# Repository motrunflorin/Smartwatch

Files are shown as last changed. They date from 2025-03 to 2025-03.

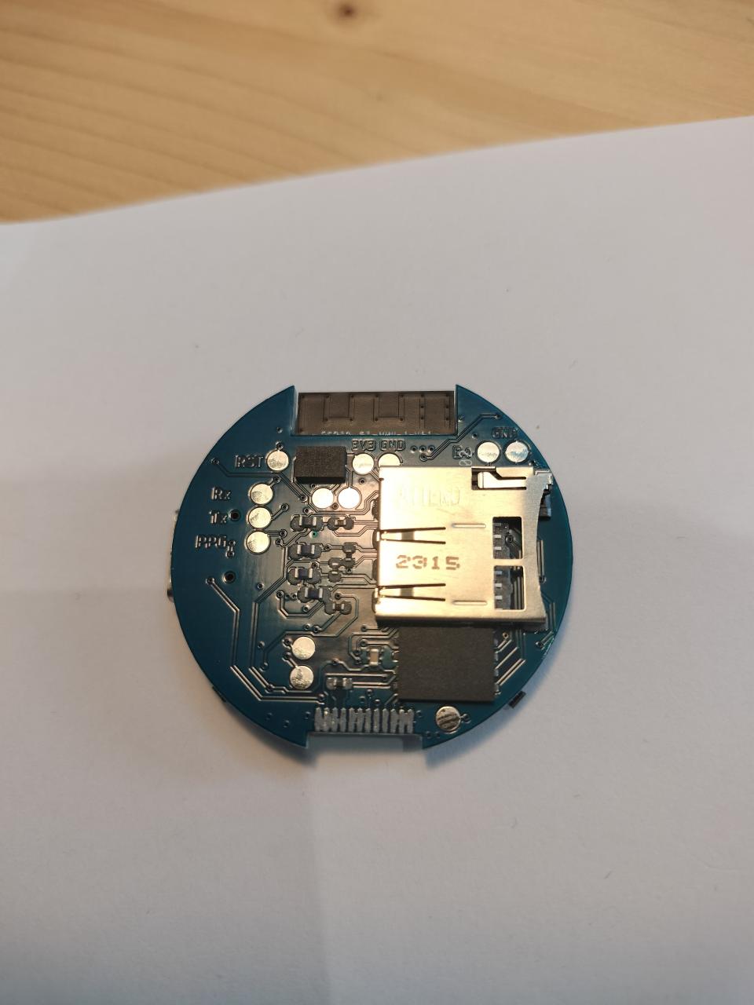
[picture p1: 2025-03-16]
bottom_layer.jpeg

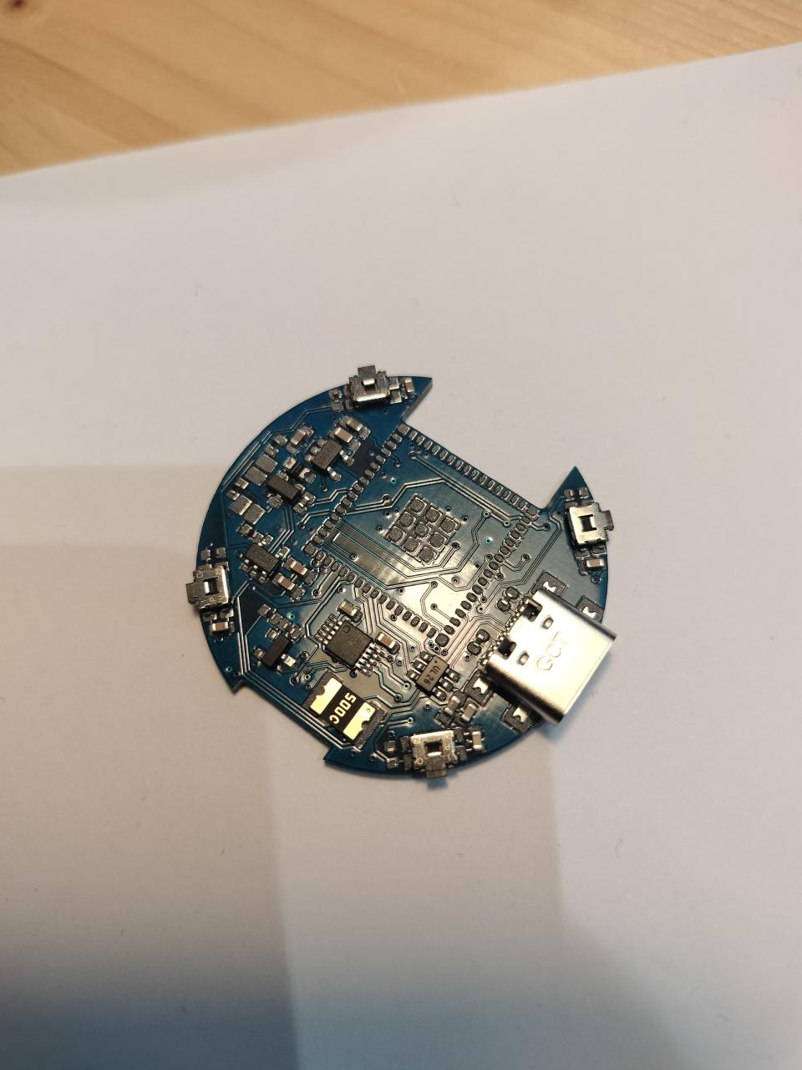
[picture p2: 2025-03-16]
top_layer.jpeg

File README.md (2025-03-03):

Functionalities:

* Wi-Fi and BLE communication via ESP32
* IMU 6-axis BMI085 for motion sensing
* DRV2605L for haptic feedback
* LiPo battery with MCP73831 charging circuit
* USB-C port for programming and charging
* 1.28-inch LCD display, 240x240 pixels for visual output
* Electronics must fit into the provided case

(All datasheets and schematics are in the Components folder)

Constraints:

* No straight angles in traces.
* Power traces must meet the required dimensions.
* Decoupling capacitors (100nF) should be placed as close as possible to the power pins of modules and ICs.
* For double-sided boards, avoid vias in power traces.
* Main components should be placed according to the mechanical dimension and placement document.
* Power traces (VCC, VUSB, VBUS, 3V3, etc.) should have a width of 0.3mm, and data signals at least 0.125mm.
* The ESP32 antenna should be placed toward the PCB edge, with the PCB cutout beneath it.

Notes and Recommendations:

* Use SMD resistors and capacitors in 0402 package, unless specified otherwise (e.g., 0603, tantalum).
* Component placement should be on the TOP layer (except for test pads, SD card socket, LCD connector, and NOR Flash).
* Routing can be on both top and bottom layers. If using two layers, ensure the ground plane is appropriately designed.
* For DRC checks, load the verification file from the provided archive.
* Apply Via Stitching between the two ground planes, especially near the ESP32 module.
* Ignore "Only INPUT pins on NET ID" error.
* Do not route signals under the ESP32 antenna; the area beneath it must be cut out to minimize interference.
* Errors due to button, header, and USB port placement are disregarded.
* Test pads should be placed only on the back of the PCB, clearly marked in silkscreen with signal names.
* Use the provided library ([hector_watch.zip file]) for component symbols and footprints, except for:
    - Buttons ([button.pdf file])
    - LCD connector (draw your own footprints based on the LCD datasheet).

Files:

* Schematics: Schematics.zip file
* DRC check: DRC_check.zip file
* PCB Dimensions & Placement: [dimensions.pdf file]

Additional Notes:

* The recommended PCB dimensions and component placement can be found in the [dimensions.pdf file], with all measurements in mm.
* The placement is just a recommendation to ensure the PCB buttons align with the physical buttons on the case.
* You are free to modify the placement, as long as you also adjust the case.
* Additionally, modify the case to allow access to the SD card and USB-C port if they do not align properly.

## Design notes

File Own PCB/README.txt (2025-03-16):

for the power traces (3V3), I maintained a width of 0.3 mm, while the rest have 0.127 mm;
!! correction: due to files not being saved properly, I had sync errors between schematics and PCB, and I had to delete the 3V3 traces and modify them with a width of 0.127 mm;

I couldn't group the test pads in a regular shape, and the TX test pad is not in the grouping in order to connect it to the corresponding pin;
(initially, I designed the test pad arrangement as three distinct groups, placed as strategically as possible near the pins they needed to be connected to, in order to have the most optimal traces);

the 100 nF decoupling capacitors were placed as close as possible to the power supply pins;

the main components were placed according to the specifications in the dimensions document, with almost negligible errors, on the order of 10^-3 mm;

the ESP32 module's antenna was placed towards the outer edge of the PCB, and the PCB was cut out as precisely as possible under the antenna;

the test pads, the SD card socket, the LCD connector, and the NOR Flash circuit were placed on the Top layer;

the footprints for the buttons and the LCD display connector were made according to the datasheet;

I tried as much as possible to keep all the component groupings from the schematics together, such as the diode grouping, for example;

I also tried to position the components as close as possible to their corresponding connections from the schematics to the PCB, such as the R1-USB resistor of the USB4110-GF-A module;

ERRORS: resistors R11 and R9 were not connected as I couldn't find a viable trace;

silkscreen was done for the test pads with a width of 0.4 mm.

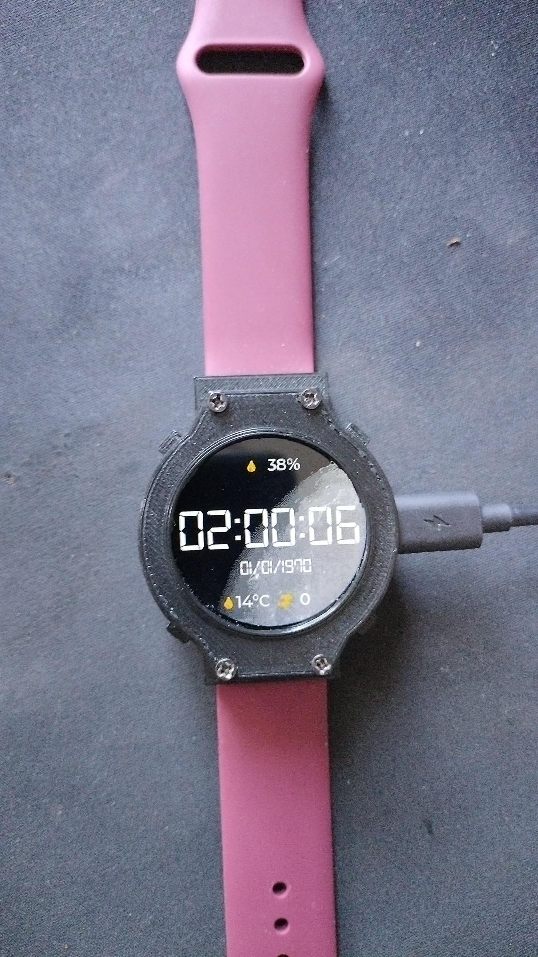
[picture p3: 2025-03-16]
finished.jpeg

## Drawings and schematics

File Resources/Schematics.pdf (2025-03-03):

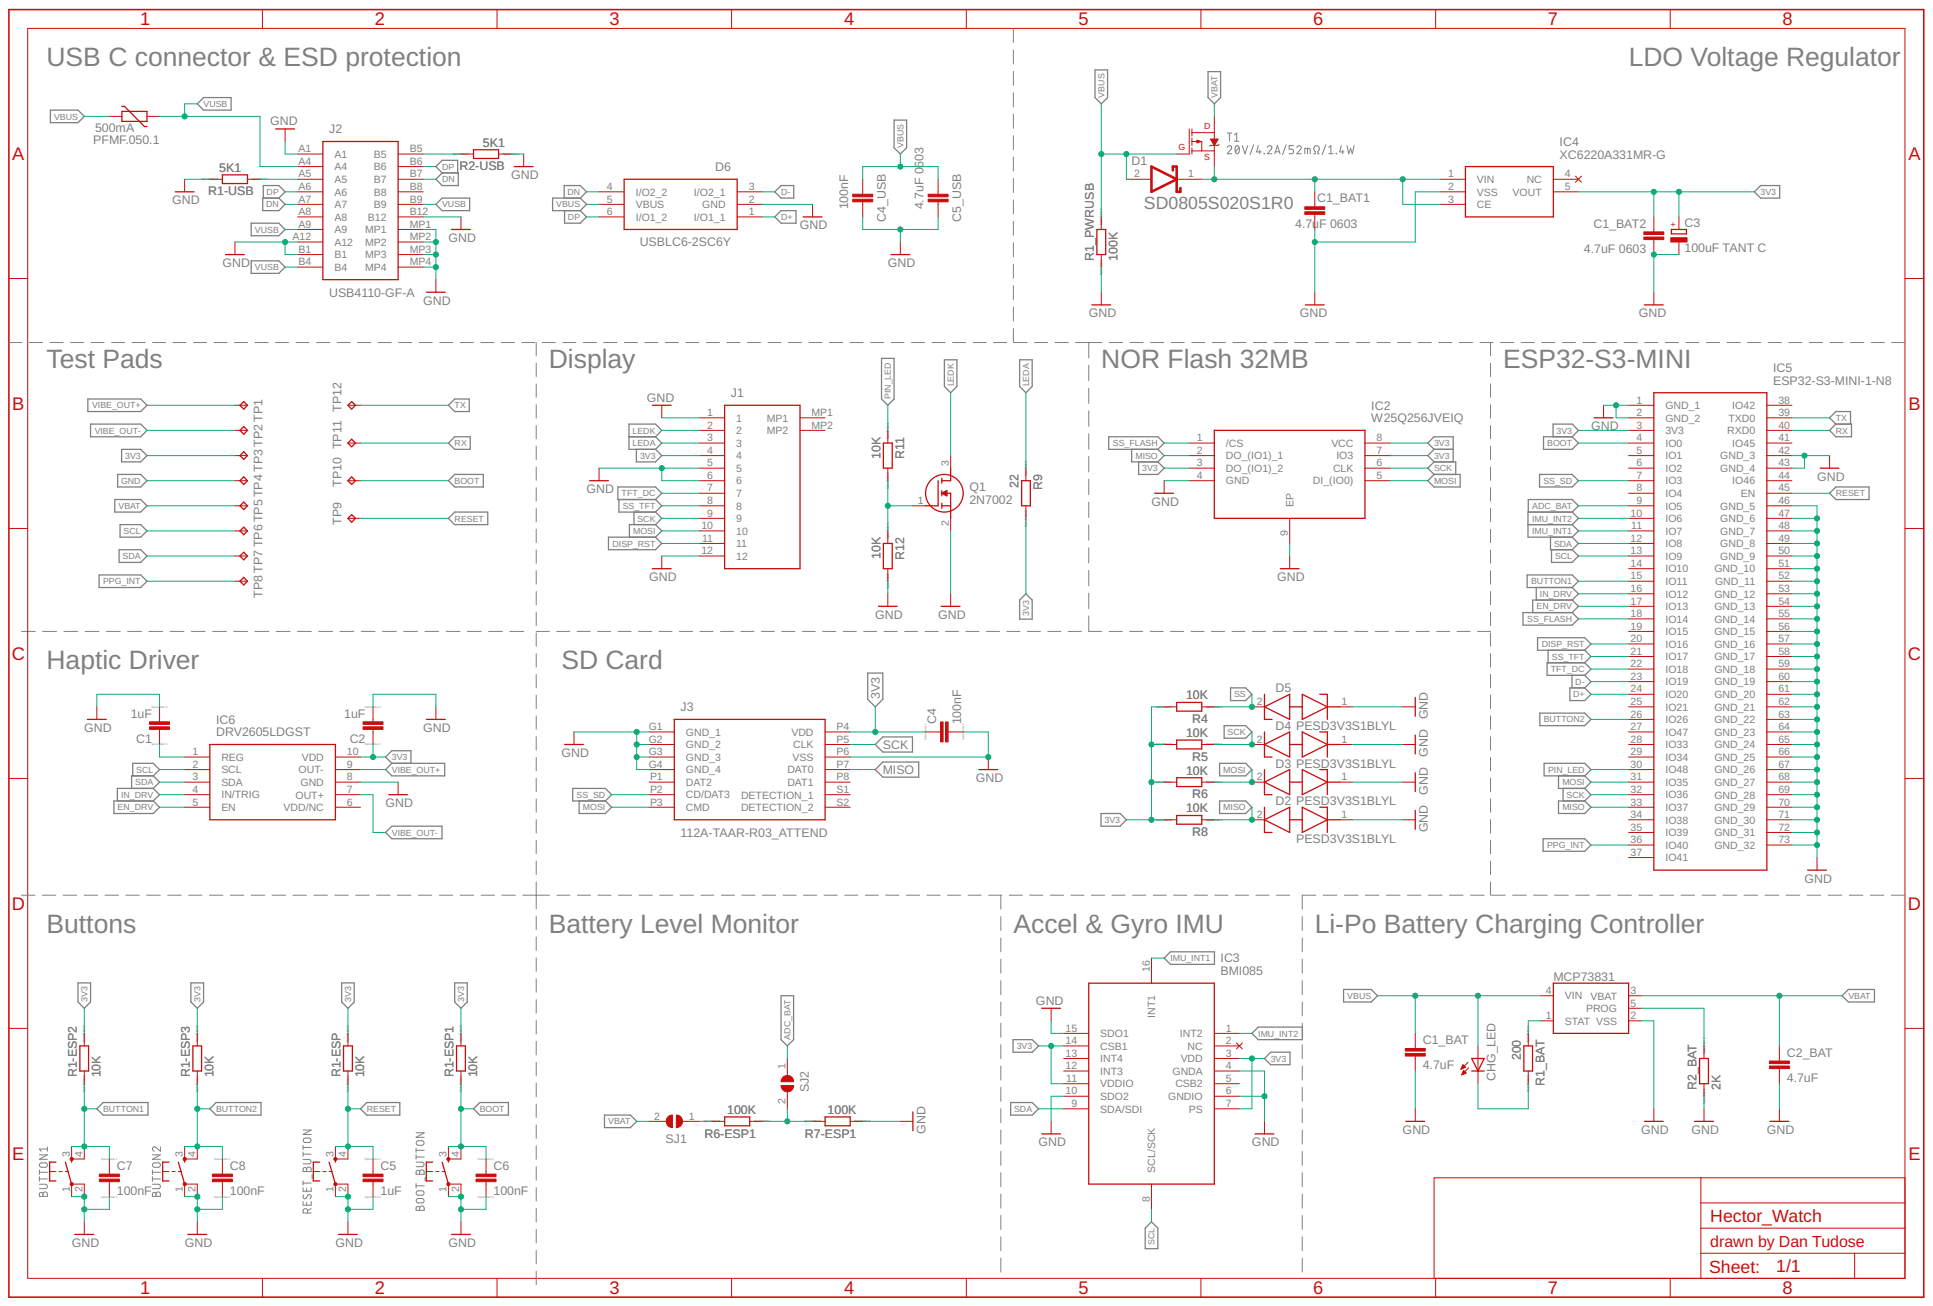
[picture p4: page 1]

USB C connector & ESD protection

SpiceOrder 1 SpiceOrder 2

SpiceOrder 1 SpiceOrder 2 SpiceOrder 1 SpiceOrder 2

IN_DRV 17 | 53 GND_13
EN_DRV 18 | 54 GND_14 55 GND_15

drawn by Dan Tudose Sheet:

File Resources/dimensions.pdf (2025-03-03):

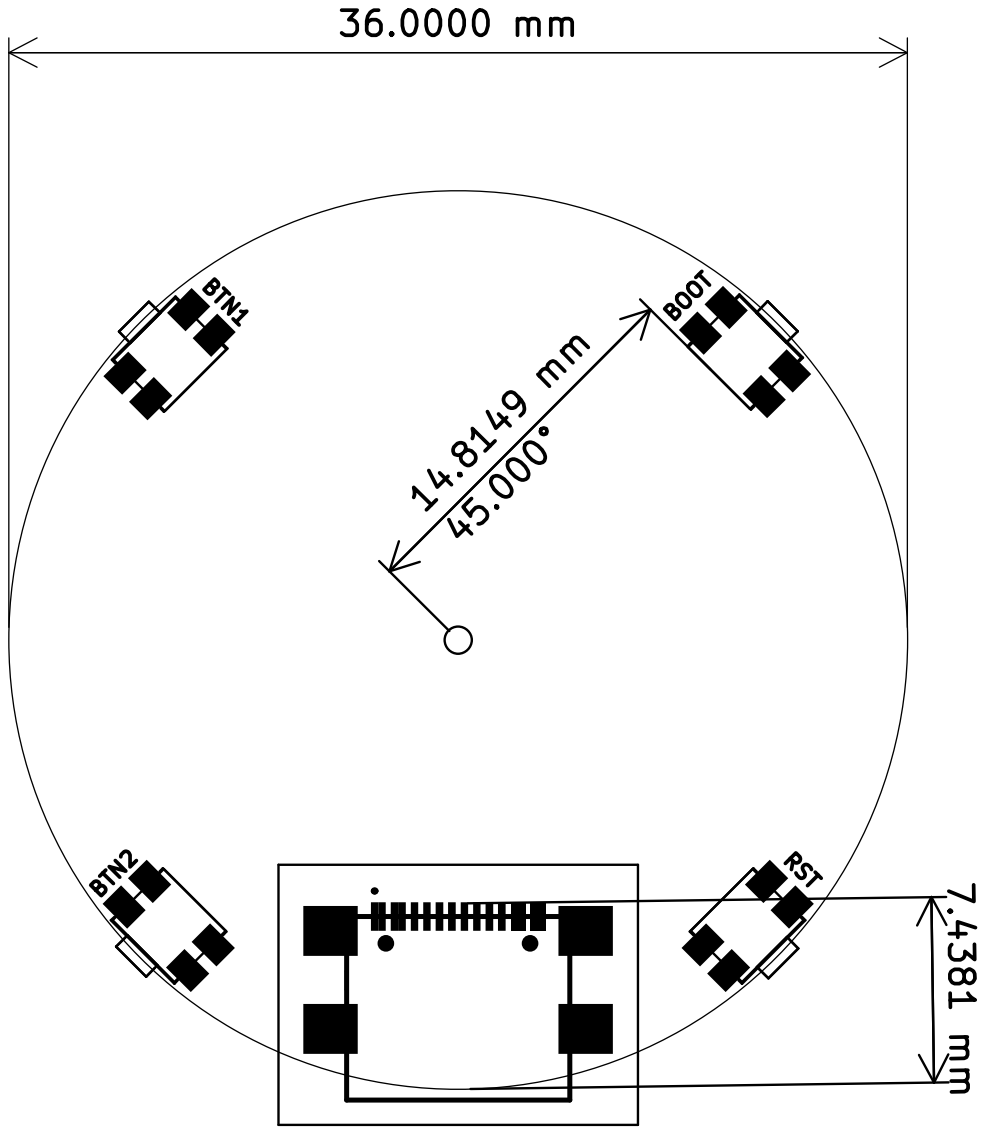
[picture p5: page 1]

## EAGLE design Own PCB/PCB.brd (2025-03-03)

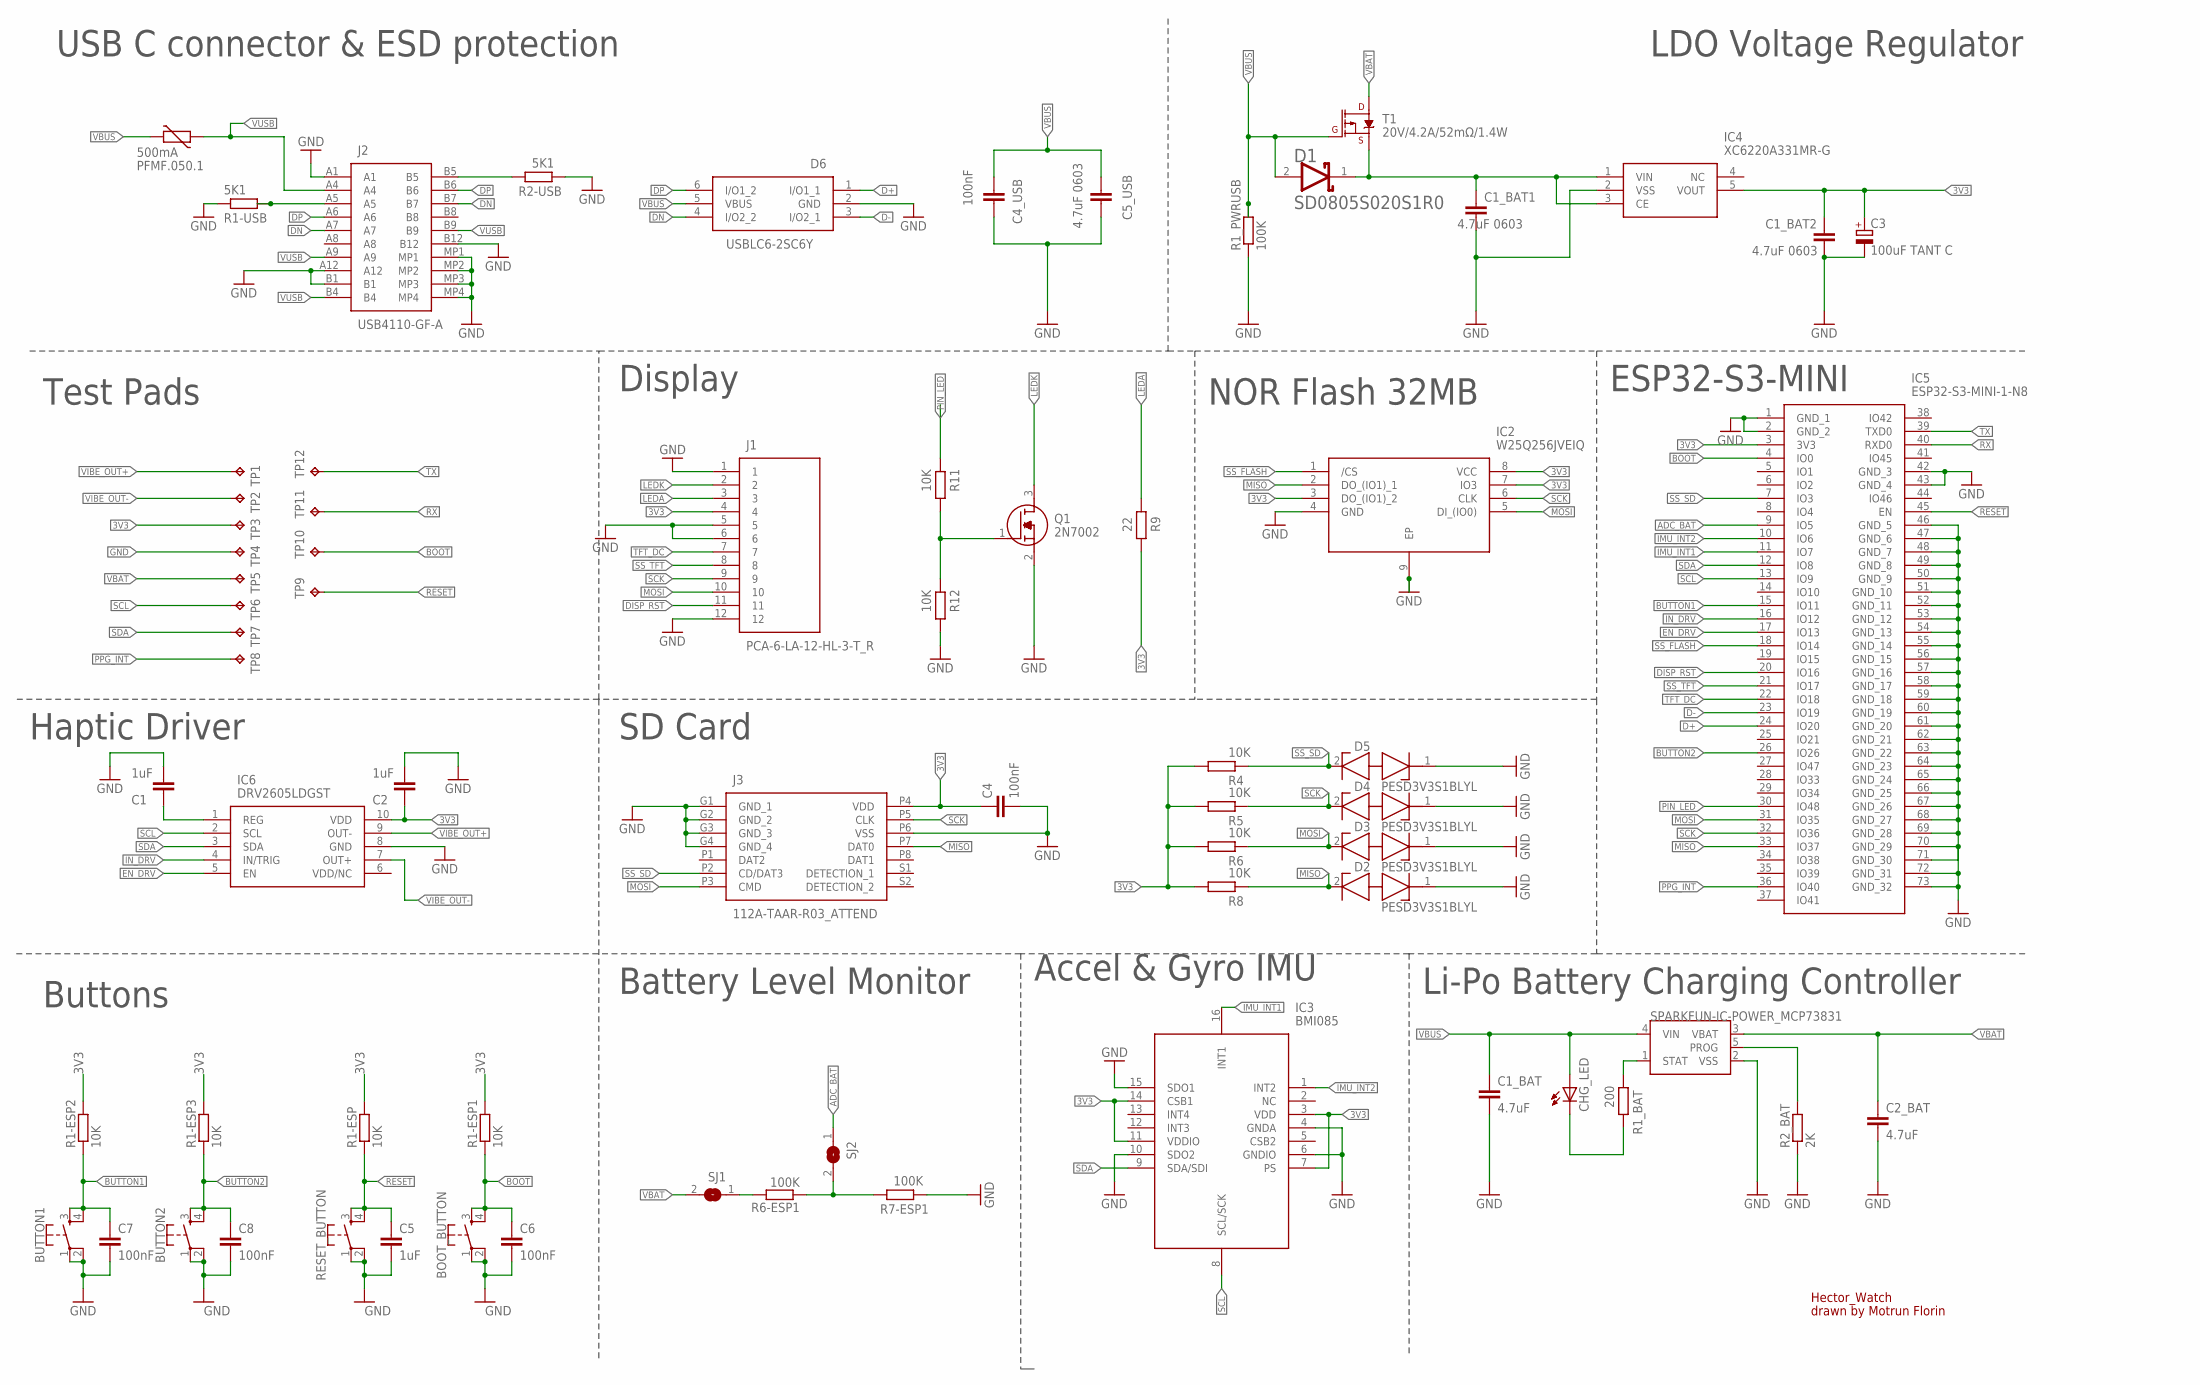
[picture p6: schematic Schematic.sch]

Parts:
BOOT_BUTTON: SPARKFUN-SWITCHES_MOMENTARY-SWITCH-SPST-2-SMD-4.6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; SPARKFUN-SWITCHES_TACTILE_SWITCH_SMD_4.6X2.8MM
BUTTON1, BUTTON2: SPARKFUN-SWITCHES_MOMENTARY-SWITCH-SPST-2-SMD-4.6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; SPARKFUN-SWITCHES_TACTILE_SWITCH_SMD_4.6X2.8MM
C1, C2, C5: 1uF; EAGLE-LTSPICE_C0402
C1_BAT, C2_BAT: 4.7uF; EAGLE-LTSPICE_C0402
C1_BAT1, C1_BAT2, C5_USB: 4.7uF 0603; RCL_C0603
C3: 100uF TANT C; CT3528
C4, C4_USB, C6, C7, C8: 100nF; EAGLE-LTSPICE_C0402
CHG_LED: ADAFRUIT_LEDCHIP-LED0603; ADAFRUIT_CHIP-LED0603
D1: AVX---SD0805S020S1R0_AVX_SD0805S020S1R0AVX_SD0805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; AVX---SD0805S020S1R0_AVX_SD0805S020S1R0_0
D2, D3, D4, D5: PESD3V3S1BLYL; PESD5V0S1BL315
D6: USBLC6-2SC6Y; SOT95P280X145-6N
IC2: W25Q256JVEIQ; SON127P800X600X80-9N
IC3: BMI085
IC4: XC6220A331MR-G; SOT95P280X120-5N
IC5: ESP32-S3-MINI-1-N8; ESP32S3MINI1N8
IC6: DRV2605LDGST; SOP50P490X110-10N
J1: PCA-6-LA-12-HL-3-T_R; PCA6LA12HL3TR
J2: USB4110-GF-A; USB4110GFA
J3: 112A-TAAR-R03_ATTEND; 112ATAARR03ATTEND
PFMF.050.1: 500mA; VARISTOR_CT/CN1812
Q1: 2N7002; SOT96P240X120-3N
R1-ESP, R1-ESP1, R1-ESP2, R1-ESP3, R4, R5, R6, R8, R11, R12: 10K; EAGLE-LTSPICE_R0402
R1-USB, R2-USB: 5K1; EAGLE-LTSPICE_R0402
R1_BAT: 200; EAGLE-LTSPICE_R0402
R1_PWRUSB, R6-ESP1, R7-ESP1: 100K; EAGLE-LTSPICE_R0402
R2_BAT: 2K; EAGLE-LTSPICE_R0402
R9: 22; EAGLE-LTSPICE_R0402
RESET_BUTTON: SPARKFUN-SWITCHES_MOMENTARY-SWITCH-SPST-2-SMD-4.6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; SPARKFUN-SWITCHES_TACTILE_SWITCH_SMD_4.6X2.8MM
SJ1, SJ2: SJ
T1: 20V/4.2A/52mΩ/1.4W; SPARKFUN-DISCRETESEMI_SOT23-3
TP1, TP2, TP3, TP4, TP5, TP6, TP7, TP8, TP9, TP10, TP11, TP12: TPTP20R; TP20R
U1: SPARKFUN-IC-POWER_MCP73831; SPARKFUN-IC-POWER_SOT23-5

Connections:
3V3: C1_BAT2.1, C2.2, C3.+, C4.1, IC2.3 (DO_(IO1)_2), IC2.7 (IO3), IC2.8 (VCC), IC3.3 (VDD), IC3.7 (PS), IC3.11 (VDDIO), IC3.14 (CSB1), IC4.5 (VOUT), IC5.3 (3V3), IC6.10 (VDD), J1.4, J3.P4 (VDD), R1-ESP.2, R1-ESP1.2, R1-ESP2.2, R1-ESP3.2, R4.1, R5.1, R6.1, R8.1, R9.1, TP3.TP
ADC_BAT: IC5.9 (IO5), SJ2.1
BOOT: BOOT_BUTTON.3, BOOT_BUTTON.4, C6.1, IC5.4 (IO0), R1-ESP1.1, TP10.TP
BUTTON1: BUTTON1.3, BUTTON1.4, C7.1, IC5.15 (IO11), R1-ESP2.1
BUTTON2: BUTTON2.3, BUTTON2.4, C8.1, IC5.26 (IO26), R1-ESP3.1
D+: D6.1 (I/O1_1), IC5.24 (IO20)
D-: D6.3 (I/O2_1), IC5.23 (IO19)
DISP_RST: IC5.20 (IO16), J1.11
DN: D6.4 (I/O2_2), J2.A7, J2.B7
DP: D6.6 (I/O1_2), J2.A6, J2.B6
EN_DRV: IC5.17 (IO13), IC6.5 (EN)
GND: BOOT_BUTTON.1, BOOT_BUTTON.2, BUTTON1.1, BUTTON1.2, BUTTON2.1, BUTTON2.2, C1.1, C1_BAT.2, C1_BAT1.2, C1_BAT2.2, C2.1, C2_BAT.2, C3.-, C4.2, C4_USB.1, C5.2, C5_USB.2, C6.2, C7.2, C8.2, D2.1 (K1), D3.1 (K1), D4.1 (K1), D5.1 (K1), D6.2 (GND), IC2.4 (GND), IC2.9 (EP), IC3.4 (GNDA), IC3.6 (GNDIO), IC3.10 (SDO2), IC3.15 (SDO1), IC4.2 (VSS), IC5.1 (GND_1), IC5.2 (GND_2), IC5.42 (GND_3), IC5.43 (GND_4), IC5.46 (GND_5), IC5.47 (GND_6), IC5.48 (GND_7), IC5.49 (GND_8), IC5.50 (GND_9), IC5.51 (GND_10), IC5.52 (GND_11), IC5.53 (GND_12), IC5.54 (GND_13), IC5.55 (GND_14), IC5.56 (GND_15), IC5.57 (GND_16), IC5.58 (GND_17), IC5.59 (GND_18), IC5.60 (GND_19), IC5.61 (GND_20), IC5.62 (GND_21), IC5.63 (GND_22), IC5.64 (GND_23), IC5.65 (GND_24), IC5.66 (GND_25), IC5.67 (GND_26), IC5.68 (GND_27), IC5.69 (GND_28), IC5.70 (GND_29), IC5.71 (GND_30), IC5.72 (GND_31), IC5.73 (GND_32), IC6.8 (GND), J1.1, J1.5, J1.6, J1.12, J2.A1, J2.A12, J2.B1, J2.B12, J2.MP1, J2.MP2, J2.MP3, J2.MP4, J3.G1 (GND_1), J3.G2 (GND_2), J3.G3 (GND_3), J3.G4 (GND_4), J3.P6 (VSS), Q1.2 (S), R1-USB.1, R1_PWRUSB.1, R2-USB.2, R2_BAT.1, R7-ESP1.2, R12.1, RESET_BUTTON.1, RESET_BUTTON.2, TP4.TP, U1.2 (VSS)
IMU_INT1: IC3.16 (INT1), IC5.11 (IO7)
IMU_INT2: IC3.1 (INT2), IC5.10 (IO6)
IN_DRV: IC5.16 (IO12), IC6.4 (IN/TRIG)
LEDA: J1.3, R9.2
LEDK: J1.2, Q1.3 (D)
MISO: D2.2 (K2), IC2.2 (DO_(IO1)_1), IC5.33 (IO37), J3.P7 (DAT0), R8.2
MOSI: D3.2 (K2), IC2.5 (DI_(IO0)), IC5.31 (IO35), J1.10, J3.P3 (CMD), R6.2
unnamed: J2.B5, R2-USB.1
unnamed: J2.A5, R1-USB.2
unnamed: C1.2, IC6.1 (REG)
unnamed: C1_BAT1.1, D1.1 (CATHODE), IC4.1 (VIN), IC4.3 (CE), T1.2 (S)
unnamed: CHG_LED.C, R1_BAT.1
unnamed: R6-ESP1.2, SJ1.1
unnamed: R6-ESP1.1, R7-ESP1.1, SJ2.2
unnamed: R2_BAT.2, U1.5 (PROG)
unnamed: Q1.1 (G), R11.1, R12.2
unnamed: R1_BAT.2, U1.1 (STAT)
PIN_LED: IC5.30 (IO48), R11.2
PPG_INT: IC5.36 (IO40), TP8.TP
RESET: C5.1, IC5.45 (EN), R1-ESP.1, RESET_BUTTON.3, RESET_BUTTON.4, TP9.TP
RX: IC5.40 (RXD0), TP11.TP
SCK: D4.2 (K2), IC2.6 (CLK), IC5.32 (IO36), J1.9, J3.P5 (CLK), R5.2
SCL: IC3.8 (SCL/SCK), IC5.13 (IO9), IC6.2 (SCL), TP6.TP
SDA: IC3.9 (SDA/SDI), IC5.12 (IO8), IC6.3 (SDA), TP7.TP
SS_FLASH: IC2.1 (/CS), IC5.18 (IO14)
SS_SD: D5.2 (K2), IC5.7 (IO3), J3.P2 (CD/DAT3), R4.2
SS_TFT: IC5.21 (IO17), J1.8
TFT_DC: IC5.22 (IO18), J1.7
TX: IC5.39 (TXD0), TP12.TP
VBAT: C2_BAT.1, SJ1.2, T1.3 (D), TP5.TP, U1.3 (VBAT)
VBUS: C1_BAT.1, C4_USB.2, C5_USB.1, CHG_LED.A, D1.2 (ANODE), D6.5 (VBUS), PFMF.050.1.2, R1_PWRUSB.2, T1.1 (G), U1.4 (VIN)
VIBE_OUT+: IC6.9 (OUT-), TP1.TP
VIBE_OUT-: IC6.7 (OUT+), TP2.TP
VUSB: J2.A4, J2.A9, J2.B4, J2.B9, PFMF.050.1.1

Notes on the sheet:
USB C connector & ESD protection
LDO Voltage Regulator
ESP32-S3-MINI
NOR Flash 32MB
Display
Test Pads
Haptic Driver
SD Card
Li-Po Battery Charging Controller
Accel & Gyro IMU
Battery Level Monitor
Buttons
Hector_Watch
drawn by Motrun Florin

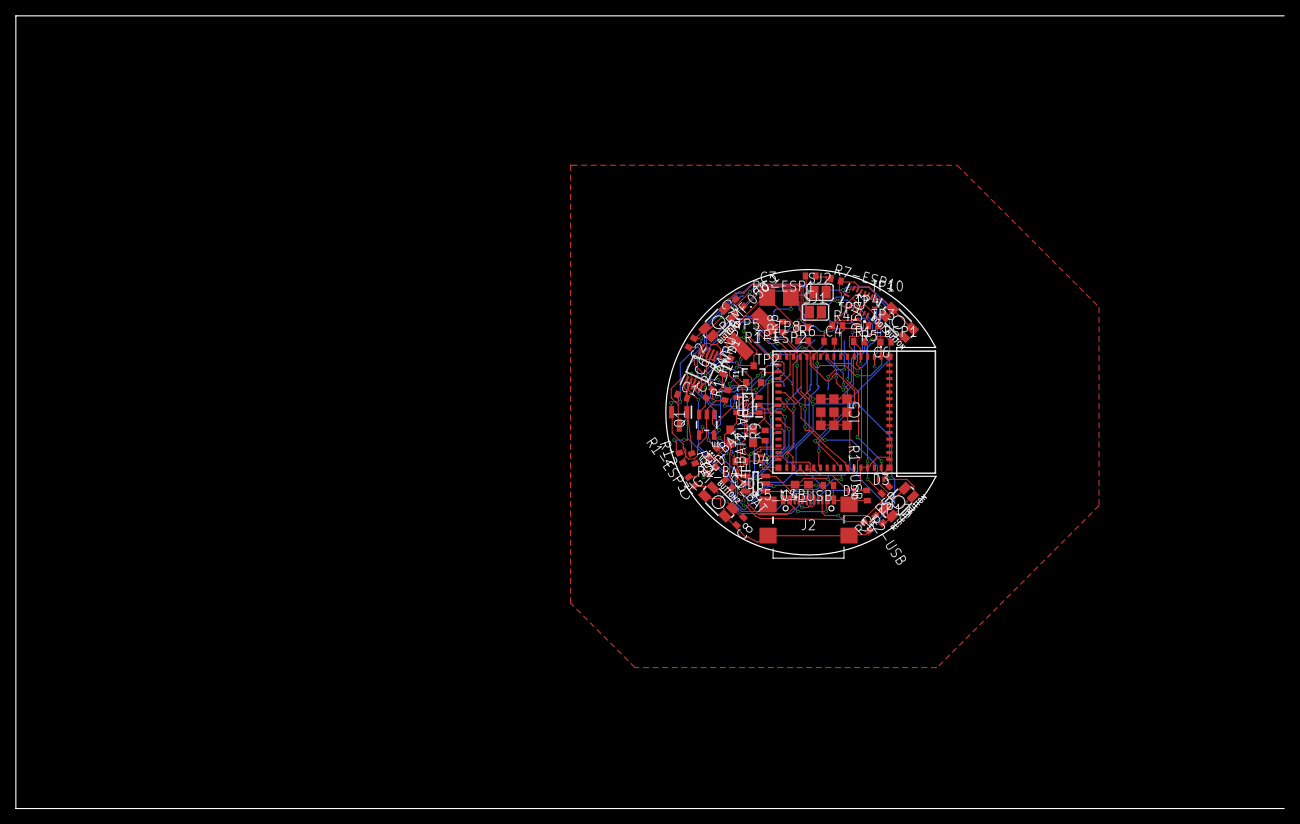
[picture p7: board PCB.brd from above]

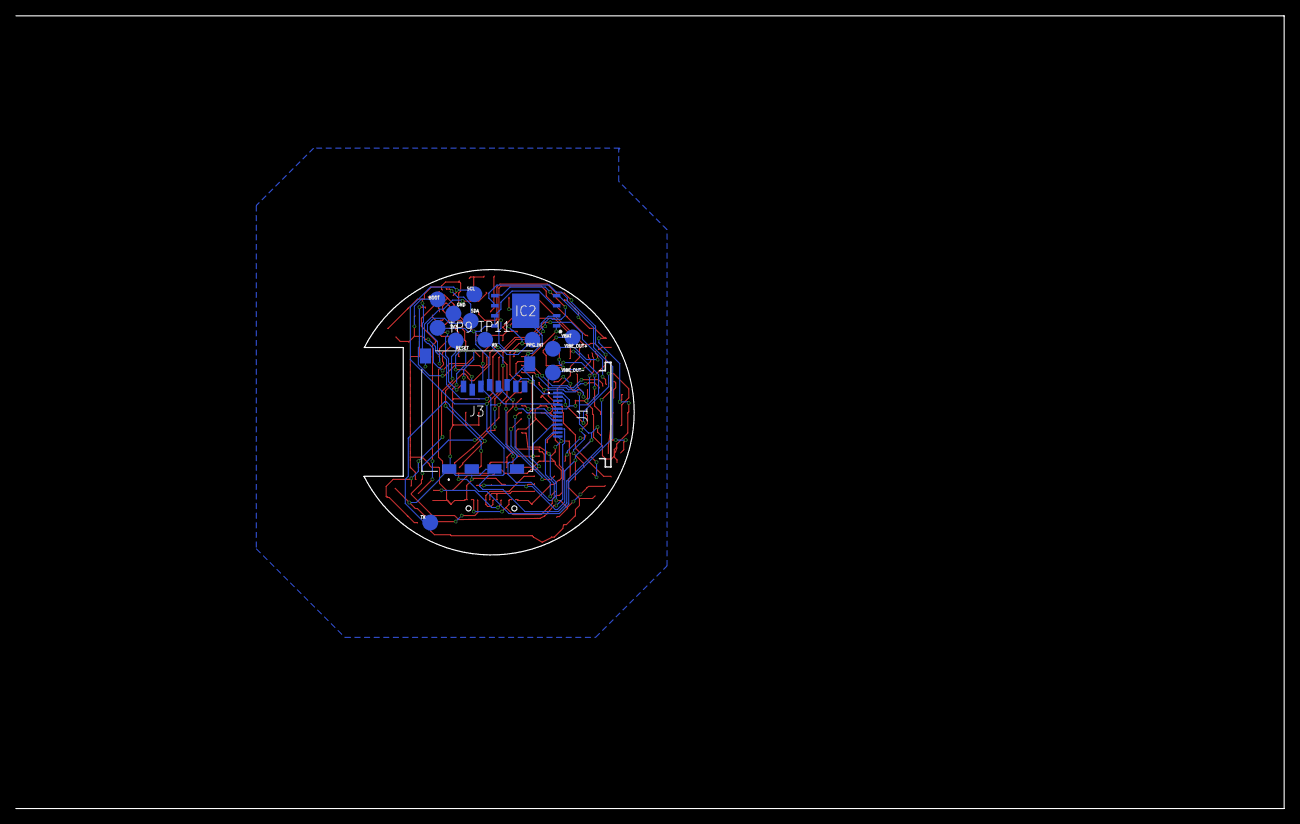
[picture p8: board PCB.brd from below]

Board: 2 copper layers, 160.0 x 100.0 mm, 69 parts (15 on the bottom side), 46 nets.
